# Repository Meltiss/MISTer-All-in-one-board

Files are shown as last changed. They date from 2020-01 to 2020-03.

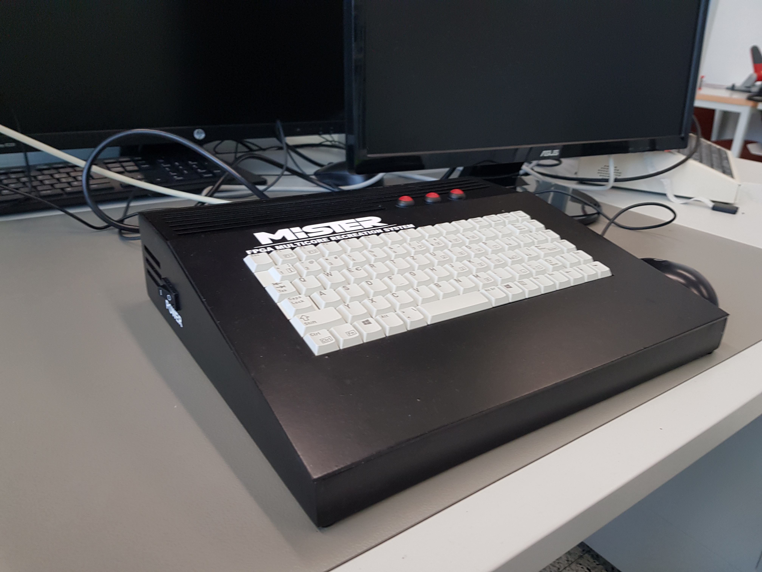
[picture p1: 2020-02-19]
MISTER CASE.jpg

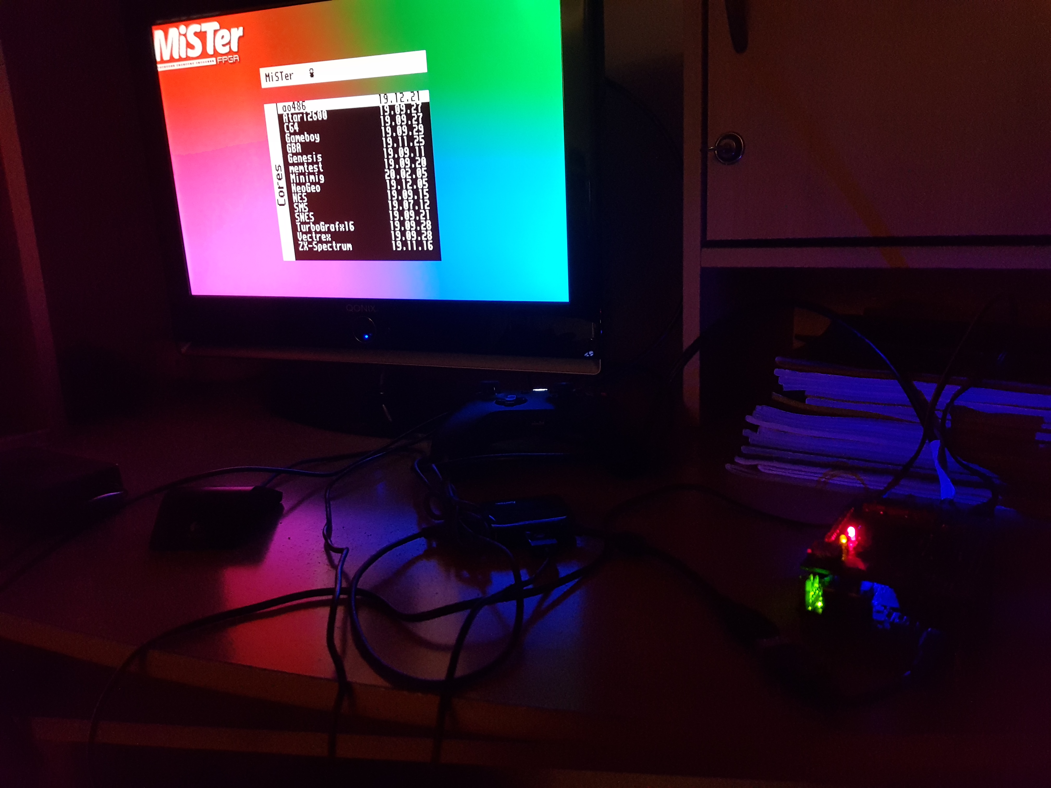
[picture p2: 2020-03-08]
Running menu.jpg

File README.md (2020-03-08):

# MISTer-All-in-one-board
# English:
This project has been made in the case of my 3rd year of aprenticeship in electronics (EPTM Valais in Switzerland).
It has been my teacher that after I ask him if I can make a project about FPGA's and retrogaming, proposed me to work on the MISTer.

The goal of my project is to make a single PCB for some of the expansions like the RAM or the RTC. Then I made a case that looks like a 80-90's computer to fit all in it.

I upload the Gerber File in case you want to do it yourself for that I also give you the list of the components i used (in french, sorry about that). Maybe I will try to find equivalent components in american shops.

So, I share the Gerber file (the zip one), as well as the schematic and pdf with a view of the both side of the PCB.

IMPORTANT : I do not guarantee that the PCB is functional for the moment, the gerber file is here in case, but I cannot say if it can work until I builded it myself.

# Features of the board :
- SDRAM (one chip -> 64MB max)
- Fan Leds and Buttons like the IO Board
- RTC (not tested yet)
- Audio Jack out
- Secondary Micro-SD (not tested yet)
- CAUTION : no VGA and Serial Port

*Update PCB V3*

This version is totally functionnal and is tested (didn't test the RTC and SD yet). It will probably be updated but it's working now. 

# Case
The case is done and has been made with a laser engraver. The case is made out of MDF and has been painted in black (yeah like the rolling stones). You can find a picture of it above.

You can find the original project here : https://github.com/MiSTer-devel
________________________________________________________________________________________________________________________________

# Français:
Ce projet a été conçu pour un travail scolaire d'électronique de 3ème année à l'EPTM du Valais en Suisse. Le professeur qui a supervisé mon projet m'a poposé de travailler sur le MISTer après lui avoir demandé si mon travail pouvait porter sur les FPGA et le retrogaming.

Le but de ce projet a donc été de concevoir un PCB regroupant la plupart des extensions comme la RAM et la RTC en un. Puis ensuite faire un boitier style ordinateur des années 80-90.

Je mets en ligne le fichier Gerber au cas où vous voudriez le faire vous-même, pour cela je vous donne également la liste des composants que j'ai utilisés. J'essaierai peut-être de trouver des composants équivalents dans des magasins américains.

Donc, je partage le fichier Gerber (le fichier zip), ainsi que la schématique et des pdf avec la vue des deux côtés du PCB.

IMPORTANT : Je ne garantis pas la fonctionnalité du PCB pour l'instant, le fichier gerber est disponible si jamais vous voulez quand même tester, mais je ne peux pas dire si le PCB marche avant d'avoir fini de le monter moi-même.

# Fonctionnalités de la carte:
- SDRAM (Un IC donc 64MB au max)
- Ventilateurs, Leds et Buttons comme l'IO Board
- RTC (pas encore testé)
- Sortie Audio Jack
- Micro-SD secondaire (pas encore testé)
- ATTENTION : pas de VGA et de port série

*Mise à jour PCB V3*

Cette version est totallement fonctionnel et testée (hors RTC et SD). Elle va sans doute encore être améliorée mais elle fonctionne bien. 

# Boîtier
Le boitier est terminé , il a été fait à la graveuse laser. Le tout est fait en MDF et a été peint en noir. Vous pouvez voir une photo au-dessus.

Vous pouvez trouver le projet originel ici : https://github.com/MiSTer-devel

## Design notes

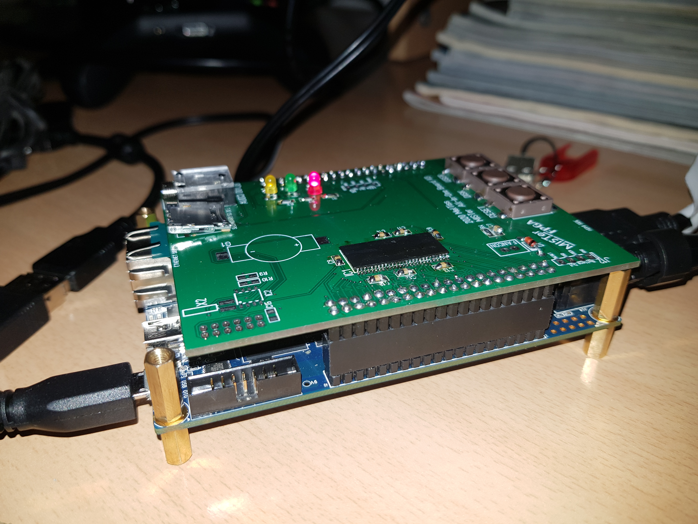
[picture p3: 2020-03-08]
PCB on DE 10 Nano.jpg

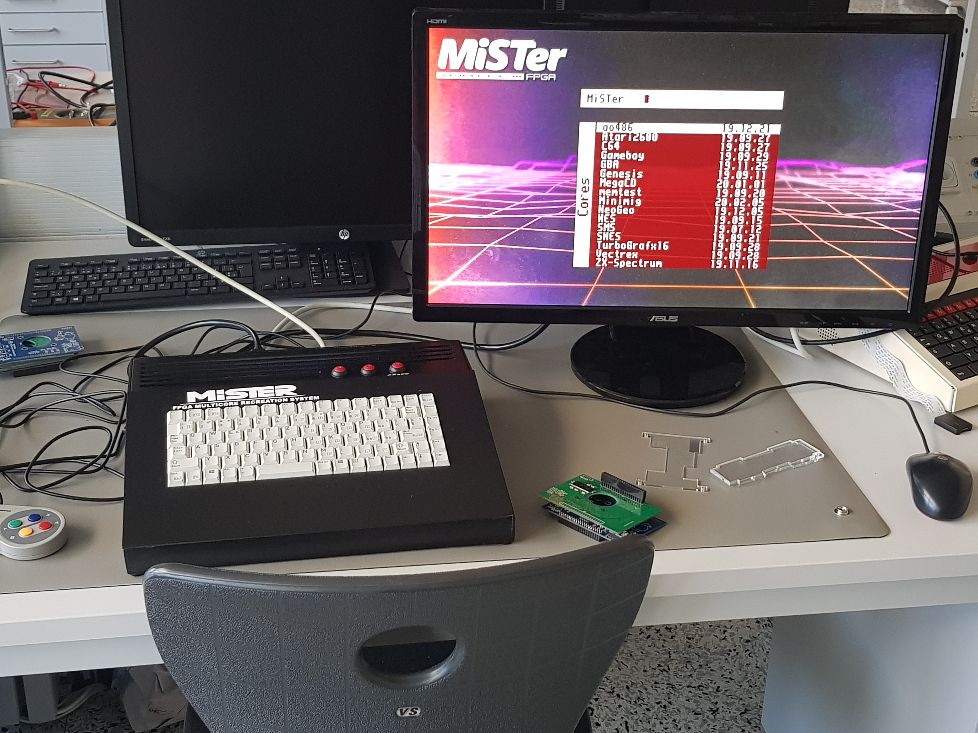
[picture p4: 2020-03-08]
Case 2.jpg

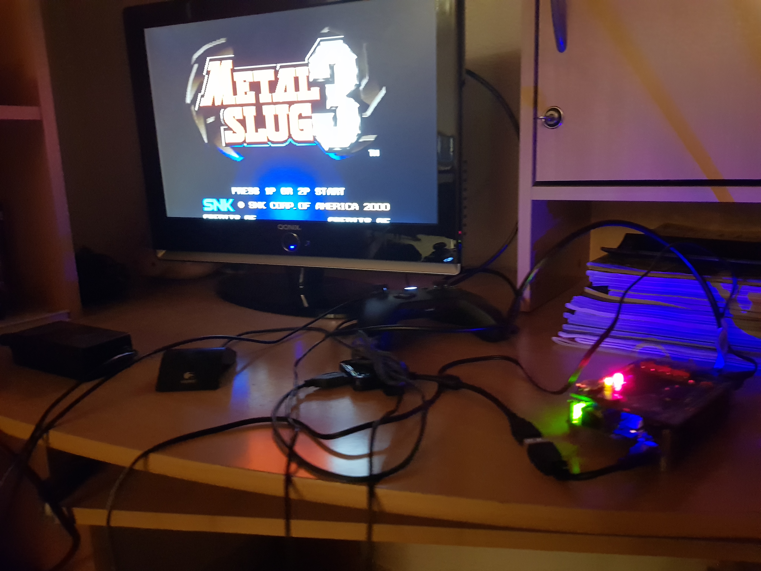
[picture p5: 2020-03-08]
Running Neo geo.jpg

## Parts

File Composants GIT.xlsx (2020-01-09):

Fournisseur | unité | nombre | art./isbn | désignation | prix unitaire
Terasic | N/A | 1 | P0496 | [DE10-Nano] DE10-Nano Board (Academic) | 109.24
Farnell | C1-4 | 4 | 3010146 | CL21B103KCANNNC - Condensateur céramique multicouche CMS, 0.01 µF, 100 V, 0805 [2012 Metric], ± 10%, X7R, CL Series | 0.01
Mouser | C5-6 | 2 | 581-F910J107MAAAJ6 | F910J107MAAAJ6 (Condo Tantale 100u) | 0.70
Farnell | C7/15 | 2 | 3010130 | CL21A106MQFNNNE - Condensateur céramique multicouche CMS, 10 µF, 6.3 V, 0805 [2012 Metric], ± 20%, X5R, CL Series | 0.02
Farnell | C9-14 | 5 | 3010149 | CL21B104KACNNNC -Condensateur céramique multicouche CMS, 0.1 µF, 25 V, 0805 [2012 Metric], ± 10%, X7R, CL Series | 0.01
Digikey | IC1 | 1 | 1450-1384-ND | AS4C32M16SB-7TIN | 15.00
Farnell | R1-3 | 3 | 2689737 | MCWR08X221 JTL - Résistance à puce CMS, 0805 [2012 Metric], 220 ohm, MCWR08 Series, 150 V, Couche épaisse, 125 mW | 0.0033 | prix total
Farnell | R4 | 1 | 2129195 | MC01W0805110K - Résistance à puce CMS, Couche épaisse, 0805 [2012 Metric], 10 kohm, Série MC, 150 V, Couche épaisse | 0.0023 | SFr.109.24
Farnell | R5-8 | 4 | 2689795 | MCWR08X561 JTL - Résistance à puce CMS, 0805 [2012 Metric], 560 ohm, MCWR08 Series, 150 V, Couche épaisse, 125 mW | 0.002 | SFr.0.04
Farnell | R9-10 | 2 | 2689783 | MCWR08X472 JTL - Résistance à puce CMS, 0805 [2012 Metric], 4.7 kohm, MCWR08 Series, 150 V, Couche épaisse, 125 mW | 0.0033 | SFr.1.41
Farnell | D1 | 1 | 9843680 | 1N4148TR - Diode signaux faibles, Une, 100 V, 200 mA, 1 V, 4 ns, 1 A | 0.10 | SFr.0.04
Farnell | LD1 | 1 | 2112100 | 703-0090 - LED, Rouge, Traversant, 3mm, 20 mA, 1.8 V, 643 nm | 0.23 | SFr.0.04
Farnell | LD2 | 1 | 2112096 | 703-0087 - LED, Vert, Traversant, 3mm, 20 mA, 2.1 V, 572 nm | 0.18 | SFr.15.00
Farnell | LD3 | 1 | 2112098 | 703-0088 - LED, Jaune, Traversant, 3mm, 20 mA, 2.1 V, 590 nm | 0.21 | SFr.0.01
Farnell | IC2 | 1 | 1823155 | MCP79410-I/SN - Calendrier/Horloge temps réel I2C à batterie avec EEPROM et ID Unique en boîtier SOIC-8 | 0.93 | SFr.0.0023
Distrelec | X1 | 1 | 301-47-319 | DM3CS-SF - MicroSD Card Connector, 8 Poles, Hirose | 1.16 | #REF!
Farnell | X2 | 1 | 9712887 | LFXTAL002997 - Cristal, 32.768 kHz, Cylindre radial, diamètre 6mm x 2mm, 12.5 pF, 20 ppm, Série WATCH-2X6 | 0.30 | #REF!
Distrelec | G1 | 1 | 169-52-501 | 3000 - Porte-piles SMD 1 x BR1216/CR1216/BR1220/CL1220/CR1220/BR1225, Keystone | 0.73 | #REF!
Mouser | S1-3 | 3 | 693-1241.1618.11 | 1241.1618.11 | 3.31 | #REF!
Distrelec | J3 | 1 | 142-70-050 | ST-3519 - Prises à encliquetage Ø3.5 mm nickelé 3 Pôles, No Brand | 2.35 | #REF!
 |  |  |  |  |  | #REF!
 |  |  |  |  |  | #REF!
 |  |  |  |  |  | #REF!
 |  |  |  |  |  | #REF!
 |  |  |  |  |  | #REF!
 |  |  |  |  |  | #REF!
 |  |  |  |  |  | #REF!

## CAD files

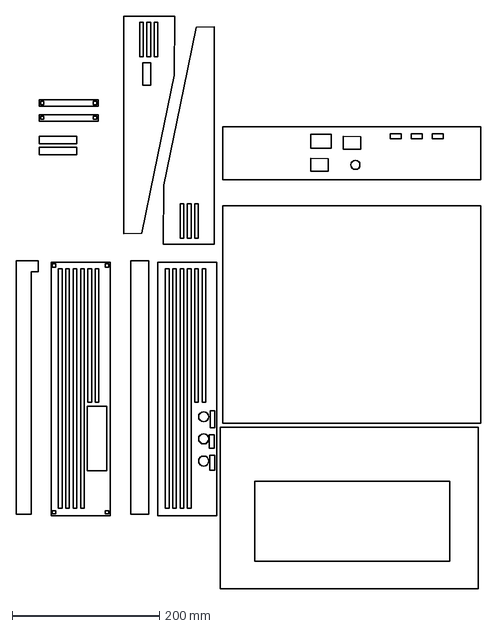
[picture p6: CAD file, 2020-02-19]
CASE.dxf
630.0 x 777.1 mm

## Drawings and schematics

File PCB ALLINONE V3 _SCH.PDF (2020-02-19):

## LED out

## Boutons out

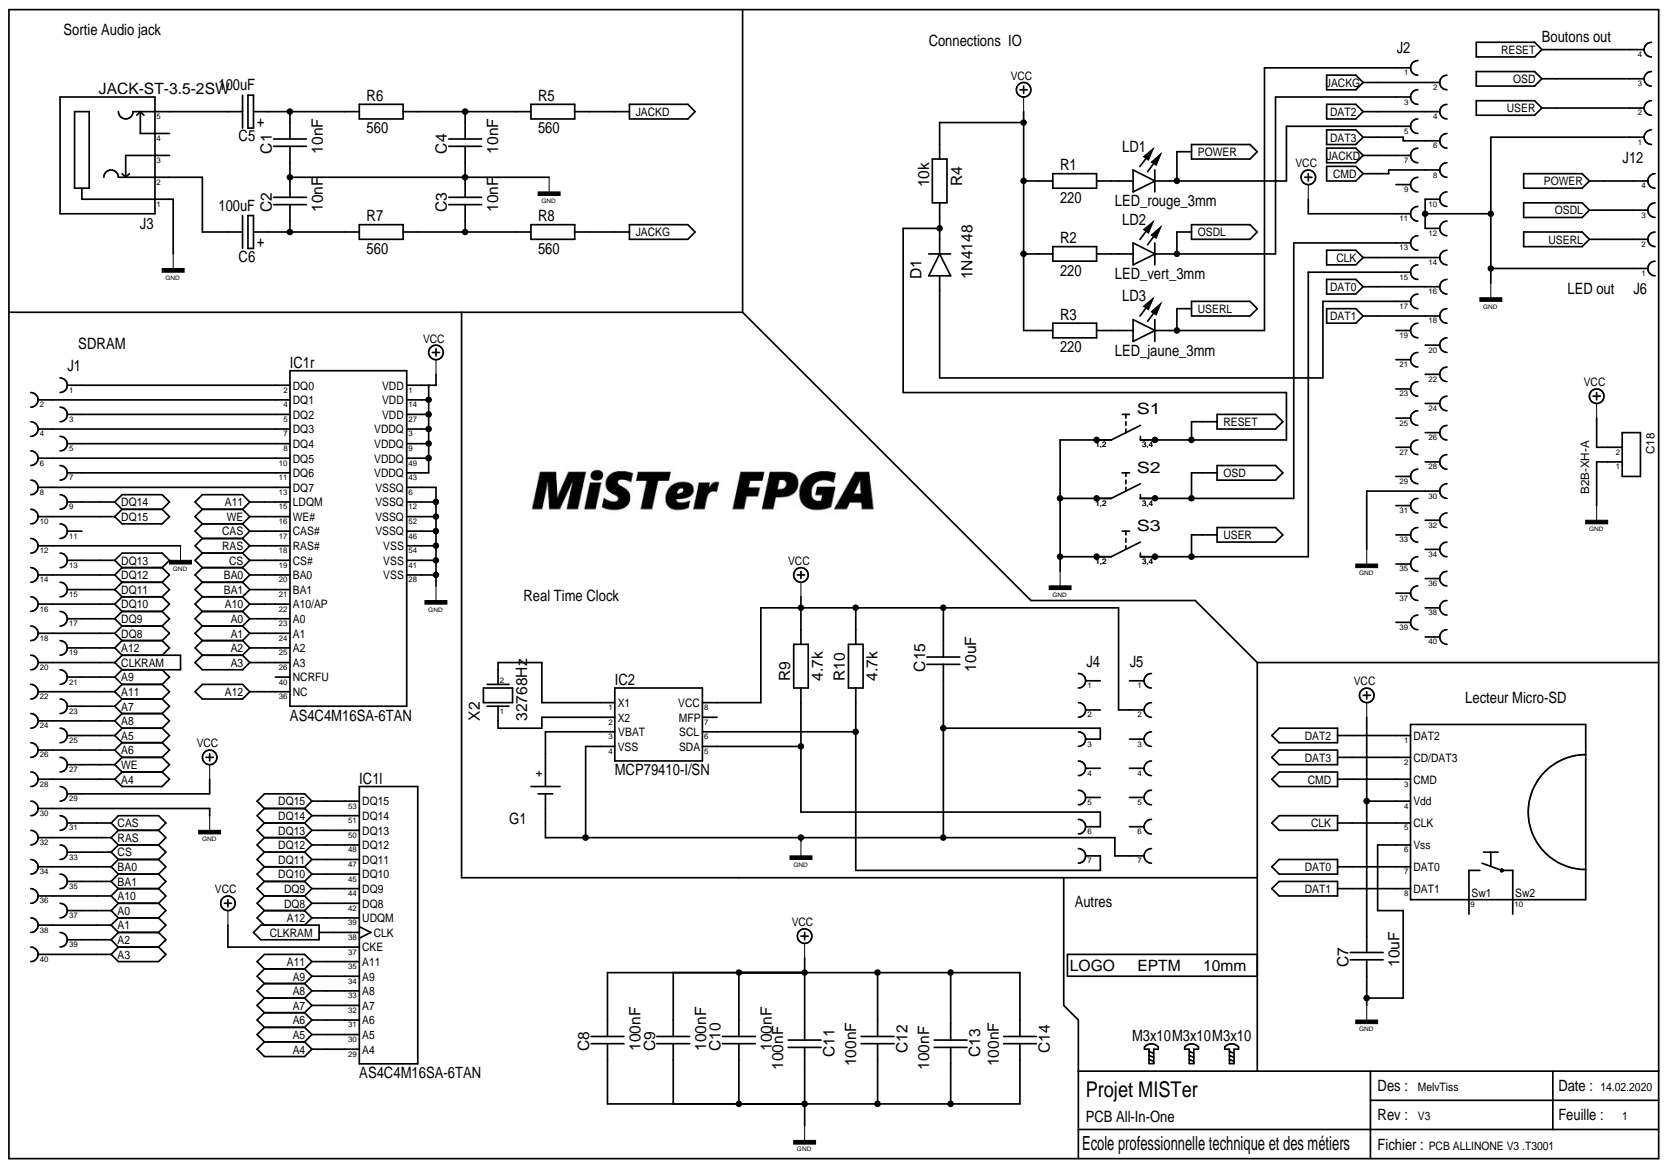
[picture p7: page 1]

Connections IO Sortie Audio jack

Ecole professionnelle technique et des métiers

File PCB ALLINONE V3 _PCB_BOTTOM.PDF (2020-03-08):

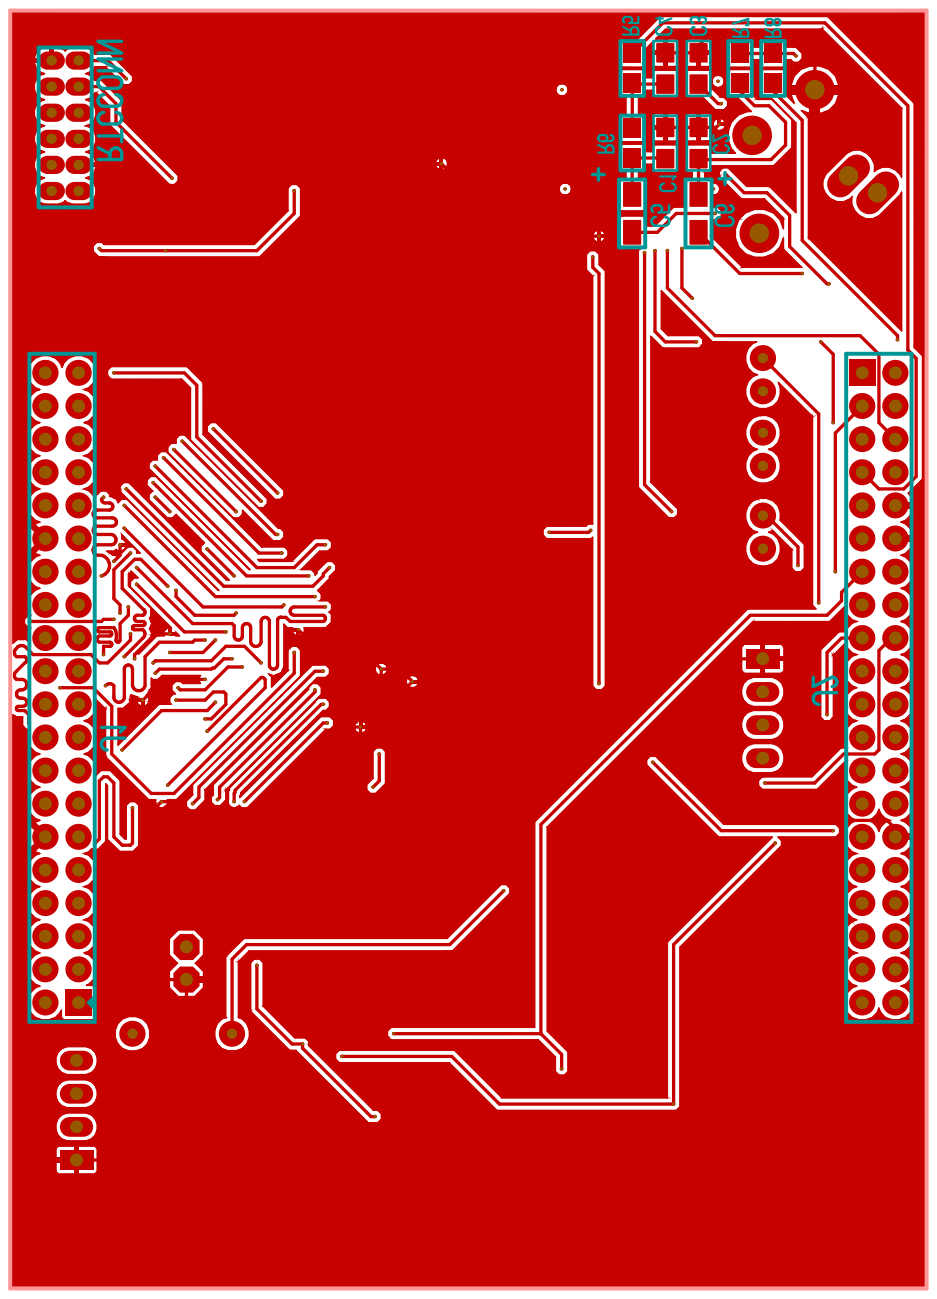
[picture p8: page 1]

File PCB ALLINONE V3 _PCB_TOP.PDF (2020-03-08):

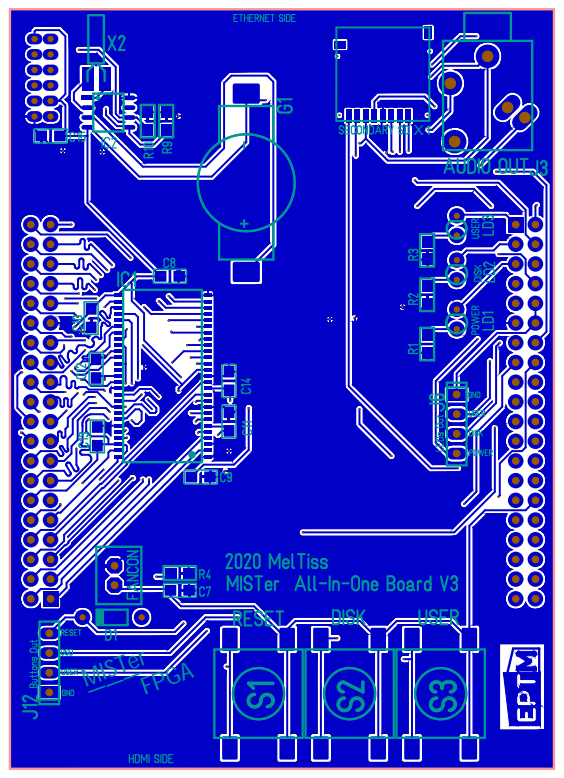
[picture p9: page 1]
MISTer ——— FPGA

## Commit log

2020-01-09 Add files via upload
    Gerber File
2020-01-09 Create PCB
